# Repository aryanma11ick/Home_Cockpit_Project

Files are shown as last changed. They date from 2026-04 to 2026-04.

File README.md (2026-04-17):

# 🛫 Home Cockpit System

A custom-built **modular home cockpit system** for flight simulation, focused on replicating real aircraft controls using **PCB design, CAD modeling, and embedded systems**.

This project combines **hardware engineering + software integration** to create a scalable and realistic cockpit environment.

---

## ✈️ Overview

The goal of this project is to design a **high-fidelity, modular cockpit system** that closely mimics real aircraft panels while remaining flexible for expansion.

Key design principles:

* 🔧 **Modularity** – Panels can be developed and used independently
* 🧩 **Scalability** – Easy to expand into a full cockpit
* 🎯 **Realism** – Accurate switch behavior and layout
* ⚡ **Integration** – Seamless connection with flight simulators

---

## 🧱 Project Structure

```text
hardware/
├── pcb/          # KiCad design files + Gerbers
└── cad/          # STEP/STL files for panels and components

firmware/         # Microcontroller code (Arduino / ESP32)

software/         # Simulator interface plugins (X-Plane, etc.)

docs/             # Documentation, diagrams, and images
```

---

## 🔧 Modules

### 🟢 Overhead External Lights Panel

* Fully functional external lighting control panel
* Supports multiple 3-position and 2-position switches
* Integrated with simulator via custom plugin
* Designed for real-time hardware ↔ simulator synchronization

---

### 🟡 Annunciator (Alert) Panel

* Displays aircraft alerts and system states
* Uses custom illuminated switches
* Modular layout for future expansion

---

### 🔘 Korry Switch Module (v2)

* Custom PCB designed in KiCad
* LED backlighting support
* Reusable module for multiple panels
* Includes CAD models for enclosure and mounting

---

## ⚙️ Technologies Used

### 🧠 Hardware

* **KiCad** – PCB design and layout
* **Fusion 360 / CAD tools** – Mechanical design and panel modeling

### 💻 Software

* **C++ (X-Plane SDK)** – Simulator interface plugins
* **Arduino / ESP32** – Firmware and hardware control

### 🔗 Tools

* **GitHub** – Version control and project management

---

## 🔁 System Architecture

```text
[Physical Switches] → [Microcontroller] → [Serial Communication]
                                  ↓
                            [Plugin / Interface]
                                  ↓
                             [Flight Simulator]
                                  ↑
                          [DataRef Feedback Loop]
```

* Closed-loop system ensures **hardware and simulator stay synchronized**
* Supports **real-time control and feedback**

---

## 🚧 Project Status

**Status:** 🟢 Active Development

### ✅ Completed

* Korry Switch PCB (v2)
* Initial CAD panel designs
* Overhead external lights panel (hardware + integration)

### 🔄 In Progress

* Firmware refinement
* Panel integration and wiring
* Simulator interface improvements

---

## 📸 Media

### Hardware Preview

<p align="center">
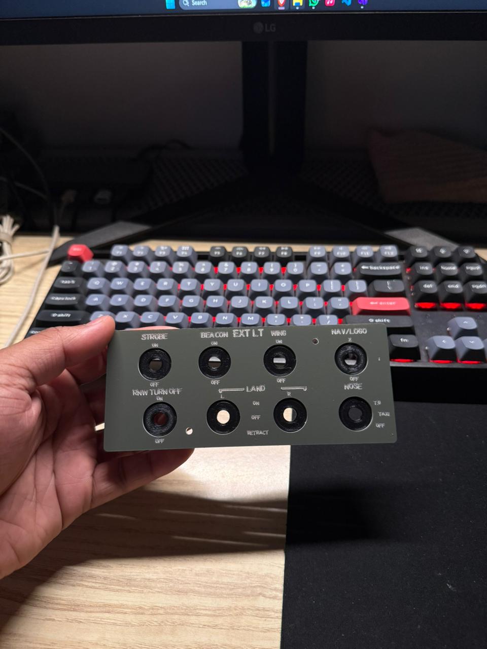
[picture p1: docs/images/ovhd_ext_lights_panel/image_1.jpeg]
  
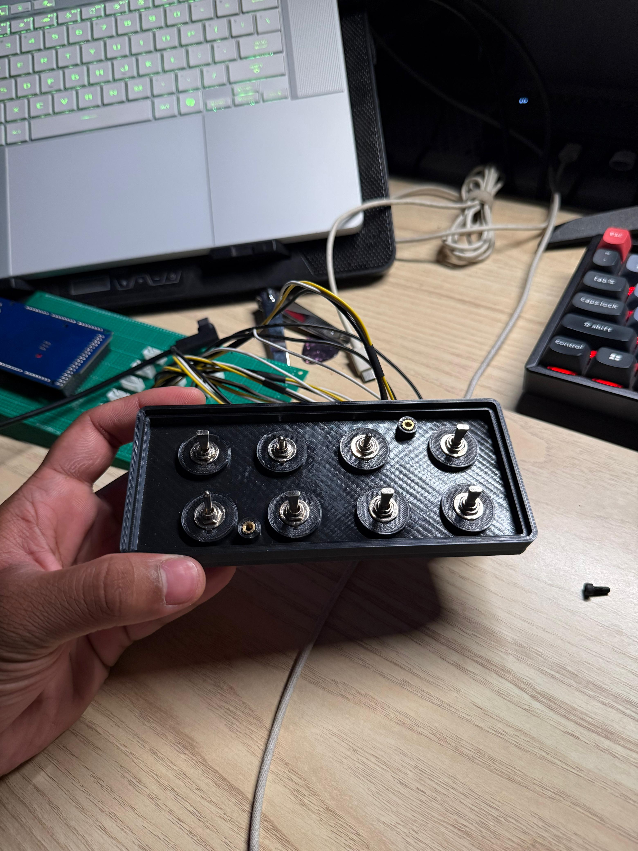
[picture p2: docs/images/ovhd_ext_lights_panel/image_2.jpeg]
  
</p>

<p align="center">
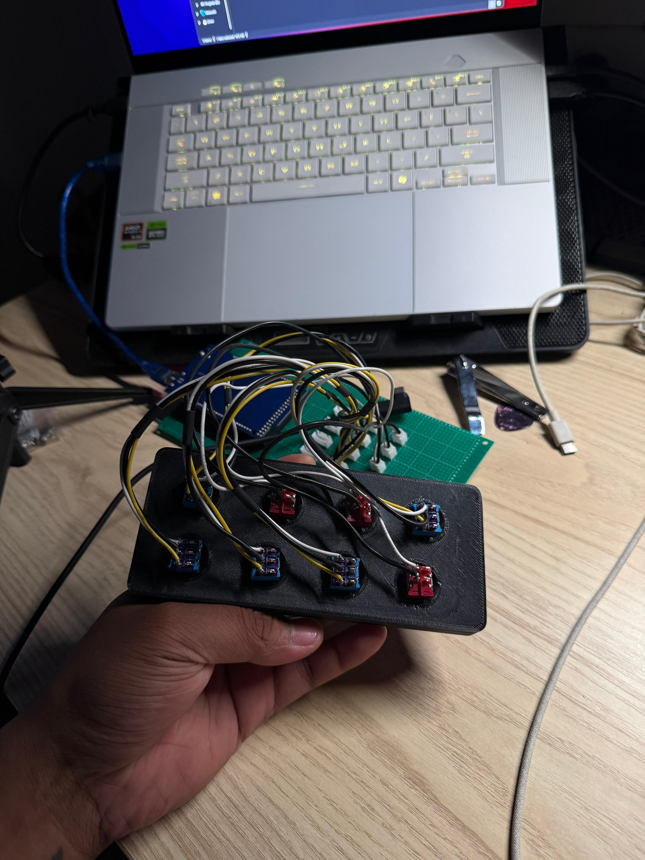
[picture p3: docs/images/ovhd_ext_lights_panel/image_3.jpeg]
  
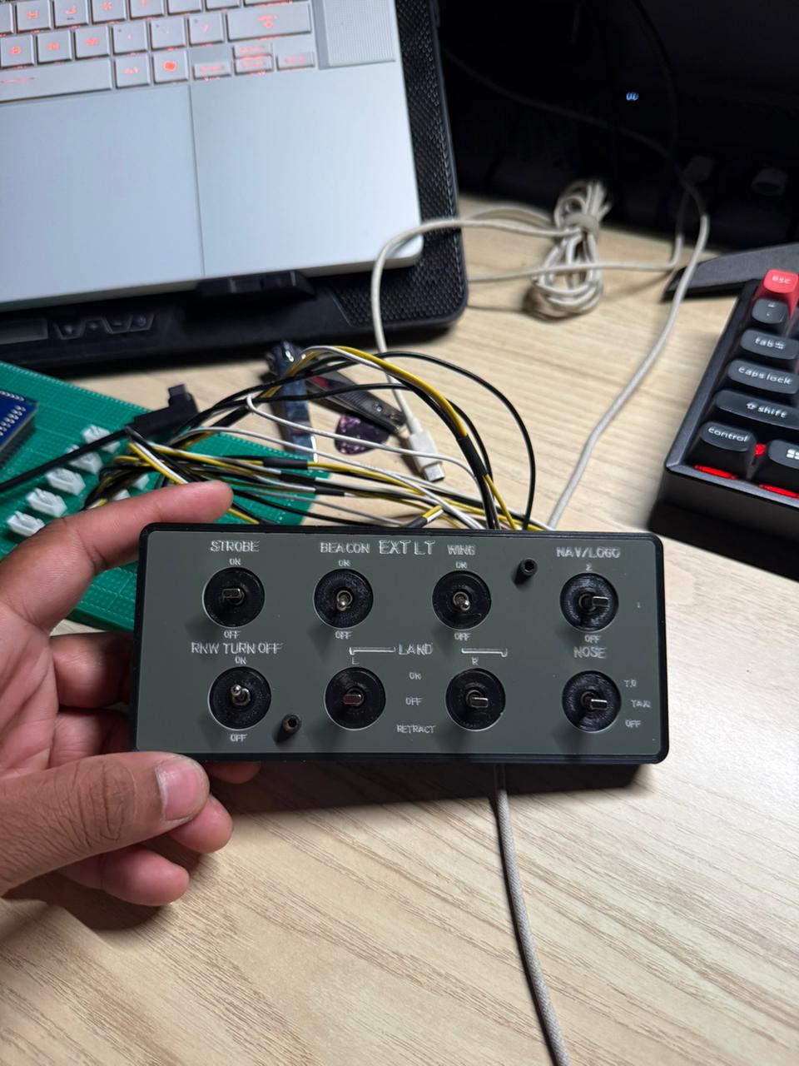
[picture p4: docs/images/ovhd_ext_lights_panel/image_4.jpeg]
  
</p>

<p align="center">
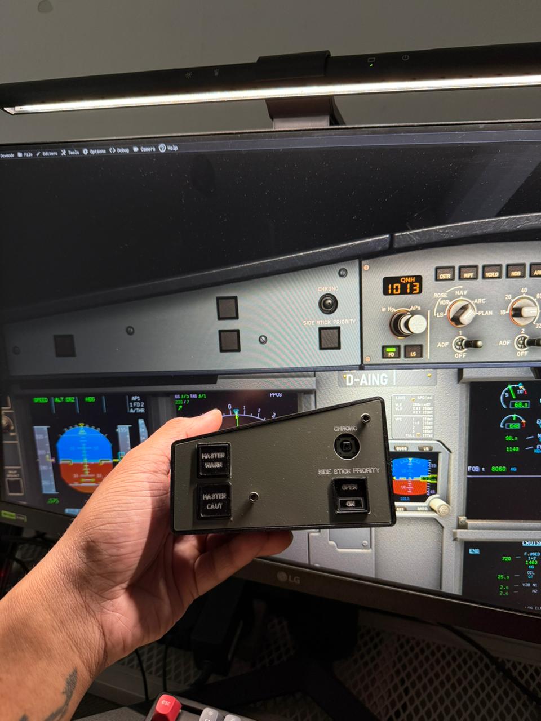
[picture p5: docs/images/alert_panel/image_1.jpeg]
  
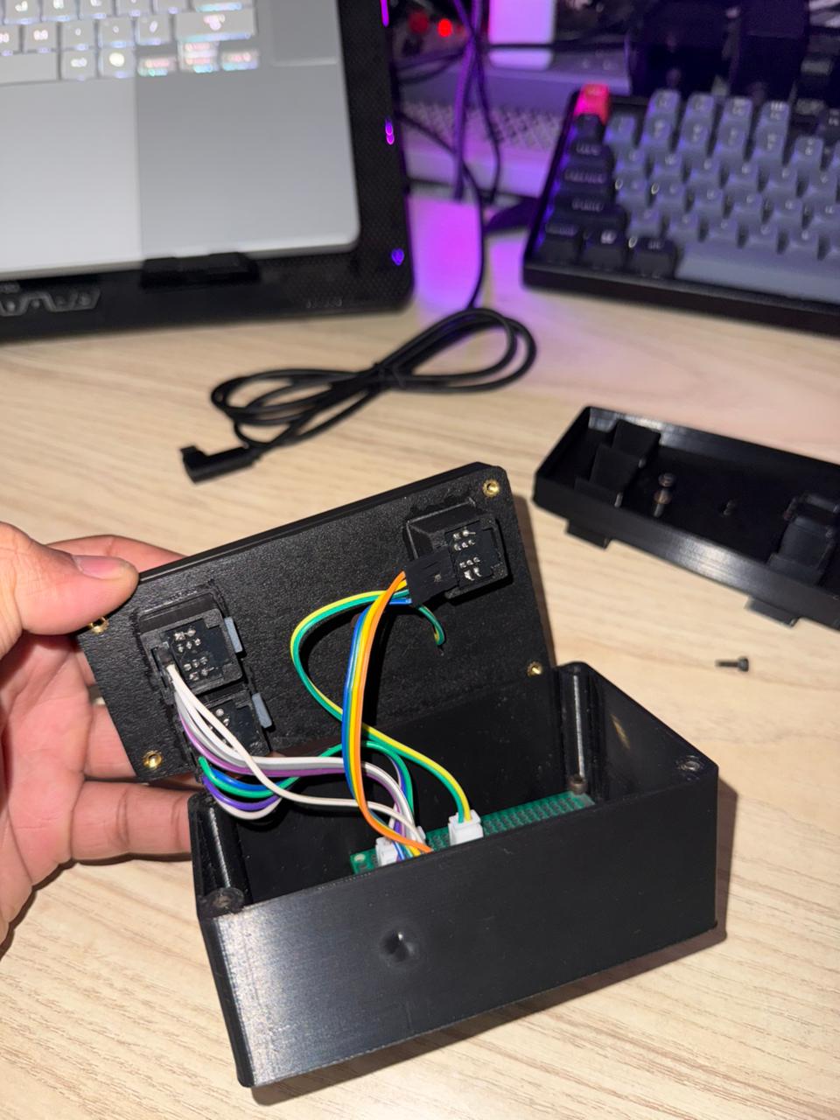
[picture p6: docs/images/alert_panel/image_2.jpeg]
  
</p>

<p align="center">
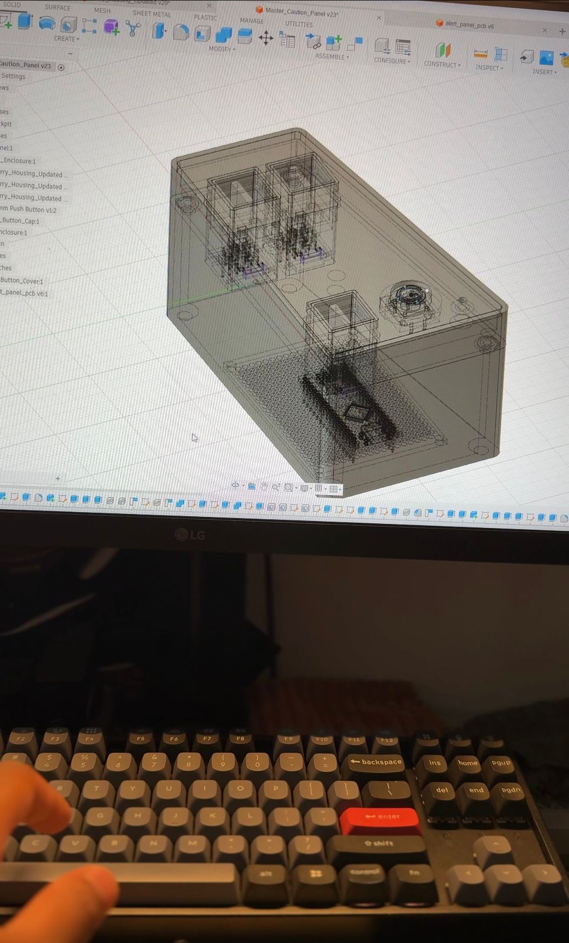
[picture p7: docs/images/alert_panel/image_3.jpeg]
  
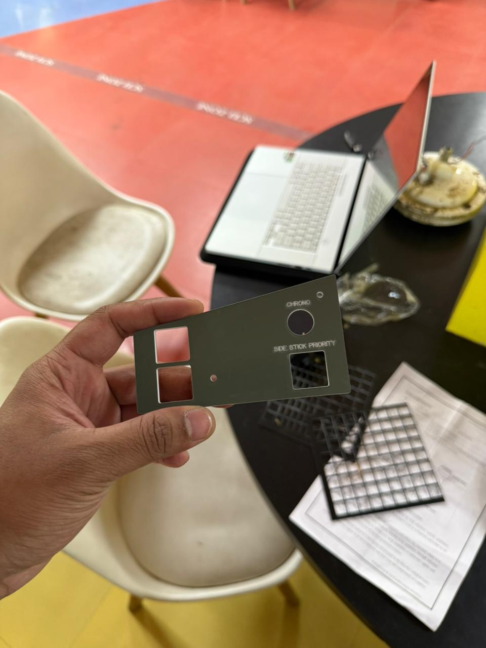
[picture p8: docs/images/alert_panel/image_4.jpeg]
  
</p>

---

## 🚀 Future Plans

* Enhanced backlighting and light diffusion
* Full overhead panel completion
* Additional cockpit modules (FCU, MCDU, etc.)
* Improved simulator integration and feedback systems
* Expansion to a complete cockpit build

---

## 👤 Author

**Aryan Mallick**
Building a full-scale home cockpit system from scratch

---

## ⭐ Notes

This project is continuously evolving with improvements in:

* Hardware design
* Firmware reliability
* Simulator integration

Contributions, suggestions, and feedback are welcome.

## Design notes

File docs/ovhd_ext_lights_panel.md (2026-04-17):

# ✈️ Arduino → ToLiss A320neo Overhead Light Panel






A custom X-Plane plugin that connects a physical Arduino-based overhead panel to the ToLiss A320neo using serial communication.

This project enables real-world cockpit switches to control aircraft lighting systems with accurate, state-driven behavior using a closed-loop control system.

---

## 🔗 Project Links

### 💻 Plugin Source Code

https://github.com/aryanma11ick/Home_Cockpit_Project/blob/main/software/sim-interface/ovhd_ext_lights_panel/plugin.cpp

### 🔌 Arduino Firmware

https://github.com/aryanma11ick/Home_Cockpit_Project/blob/main/firmware/arduino/ovhd_ext_lights_panel/ovhd_ext_lights.ino

### 🖼️ Panel Images

https://github.com/aryanma11ick/Home_Cockpit_Project/tree/main/docs/images/ovhd_ext_lights_panel

---

## 📸 Hardware Preview

<p align="center">
  
  
</p>

<p align="center">
  
  
</p>
---

## 🚀 Features

### 🔌 Hardware Integration

* Arduino-based overhead panel
* Multiple switch inputs (3-position & 2-position)
* Serial communication @ 115200 baud

---

### 💡 Supported Systems

#### 🔺 3-Position Switches

* Strobe Lights
* Nav/Logo Lights
* Landing Lights (Left & Right independent)
* Nose Light (Taxi / Takeoff / Off)

#### 🔻 2-Position Switches

* Beacon Light
* Wing Light
* RWY Turn-Off Light

---

### 🔁 Closed-Loop Control System

* Uses ToLiss animation datarefs for real-time feedback
* Compares hardware state with aircraft state
* Automatically drives switches using Up/Down commands
* Prevents desynchronization between sim and hardware

---

### ⚡ Performance Optimized

* Non-blocking serial communication
* Buffered input parsing
* Low CPU usage
* No FPS drops or simulator lag

---

## 🧠 Architecture

```text
Arduino → Serial → Plugin → Commands → Aircraft
                                ↑
                          DataRefs (feedback)
```

---

## 📡 Serial Protocol

| Code | System | Values |
| ---- | --- | --- |
| S | Strobe | 0 / 1 / 2 |
| N | Nav/Logo | 0 / 1 / 2 |
| LL | Left Landing  | 0 / 1 / 2 |
| RL | Right Landing | 0 / 1 / 2 |
| O | Nose Light | 0 / 1 / 2 |
| B | Beacon | 0 / 1 |
| W | Wing | 0 / 1 |
| R | RWY Turn Off  | 0 / 1 |

### Example

```
S:2
N:1
LL:2
RL:0
O:2
B:1
W:0
R:1
```

---

## 🧩 X-Plane Integration

### ✈️ Commands (Control)

```
toliss_airbus/lightcommands/*
```

### 📊 DataRefs (State Feedback)

```
ckpt/oh/.../anim
```

---

## 🛠️ Setup

### 1. Build Plugin

* Open project in Visual Studio
* Build as **64-bit**
* Rename output:

```
win.xpl
```

---

### 2. Install Plugin

```
X-Plane 12/Resources/plugins/ArduinoSerialPlugin/64/win.xpl
```

---

### 3. Arduino Setup

* Upload firmware
* Set baud rate: **115200**
* Match COM port in plugin

---

### 4. Run

* Load ToLiss A320neo
* Enable plugin via Plugin Admin

---

## ⚠️ Notes

* RWY Turn-Off uses command-only logic (no feedback dataref)
* Designed specifically for ToLiss Airbus aircraft
* Uses animation datarefs for accurate state tracking

---

## 🔧 Future Improvements

* LED feedback to Arduino
* Auto serial reconnect
* Cold & Dark / power logic
* Full overhead expansion

---

## 👨‍💻 Author

Aryan Mallick
Home cockpit & avionics integration project

---

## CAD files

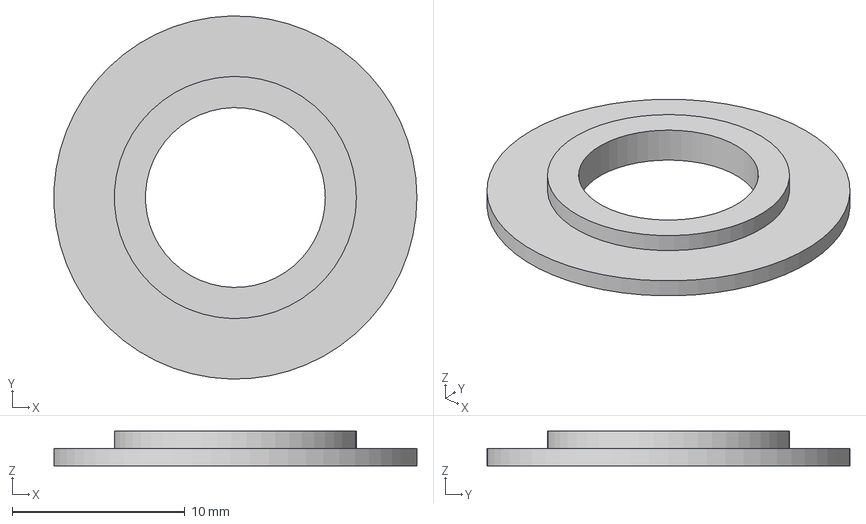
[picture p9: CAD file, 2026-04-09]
hardware/cad/step/alert_panel/chrono_button_cover.step
21.0 x 21.0 x 2.00 mm

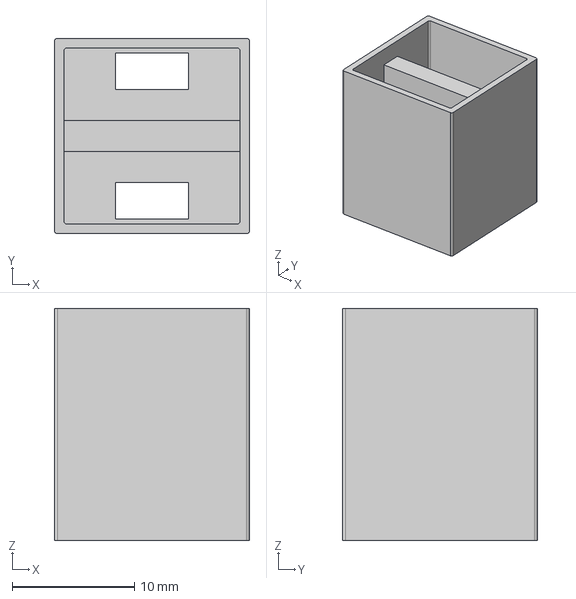
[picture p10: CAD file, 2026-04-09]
hardware/cad/step/korry_button/internal_shell.step
16.0 x 16.0 x 19.0 mm

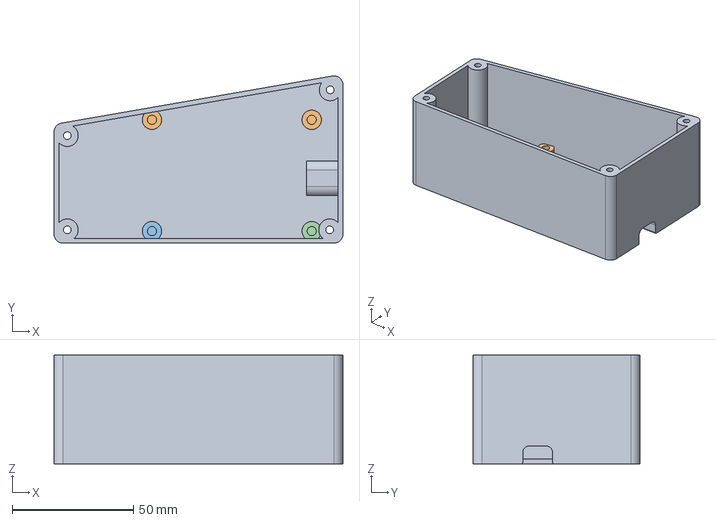
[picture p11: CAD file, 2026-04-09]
hardware/cad/step/alert_panel/back_enclosure.step
119.4 x 69.1 x 45.0 mm

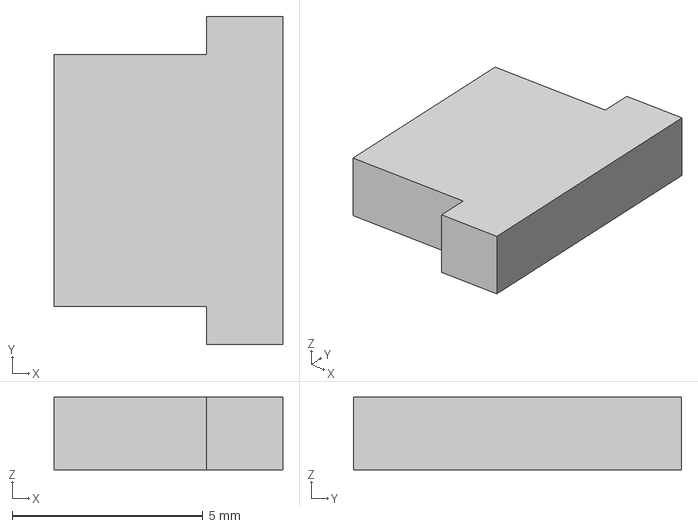
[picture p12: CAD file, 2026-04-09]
hardware/cad/step/korry_button/pcb_lock.step
6.00 x 8.60 x 1.90 mm

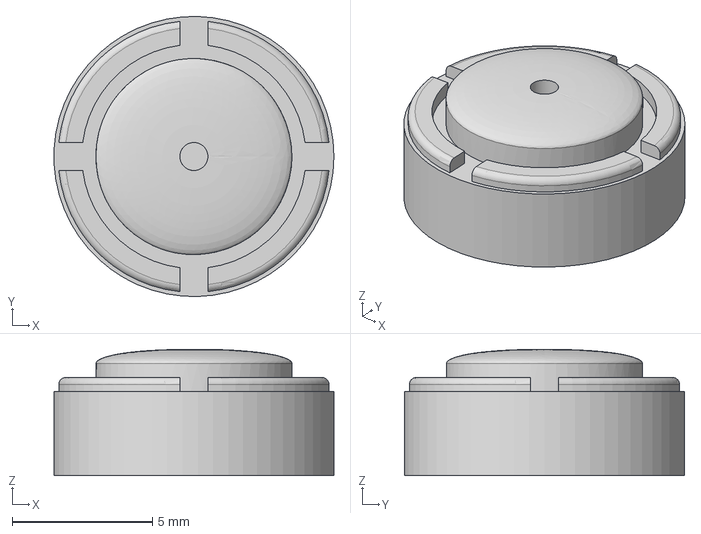
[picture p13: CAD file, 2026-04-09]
hardware/cad/step/alert_panel/chrono_button_cap.step
9.99 x 10.00 x 4.50 mm

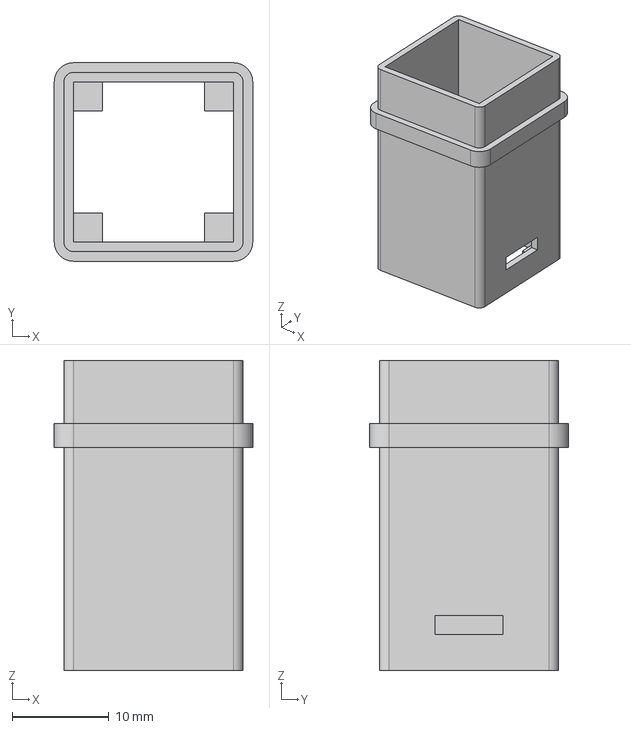
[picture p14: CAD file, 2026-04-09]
hardware/cad/step/korry_button/external_shell.step
20.5 x 20.5 x 32.0 mm

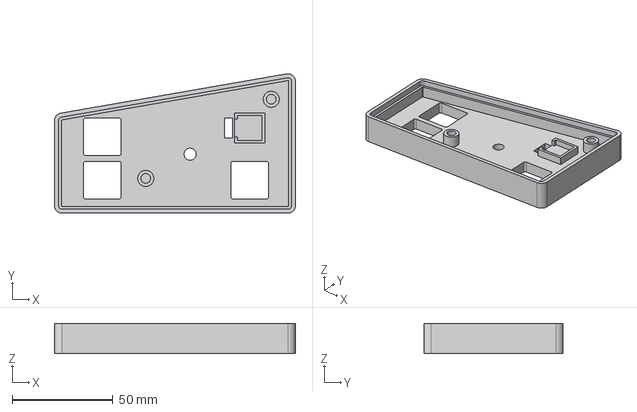
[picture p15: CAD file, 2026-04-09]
hardware/cad/step/alert_panel/middle_enclosure.step
119.4 x 69.1 x 15.0 mm

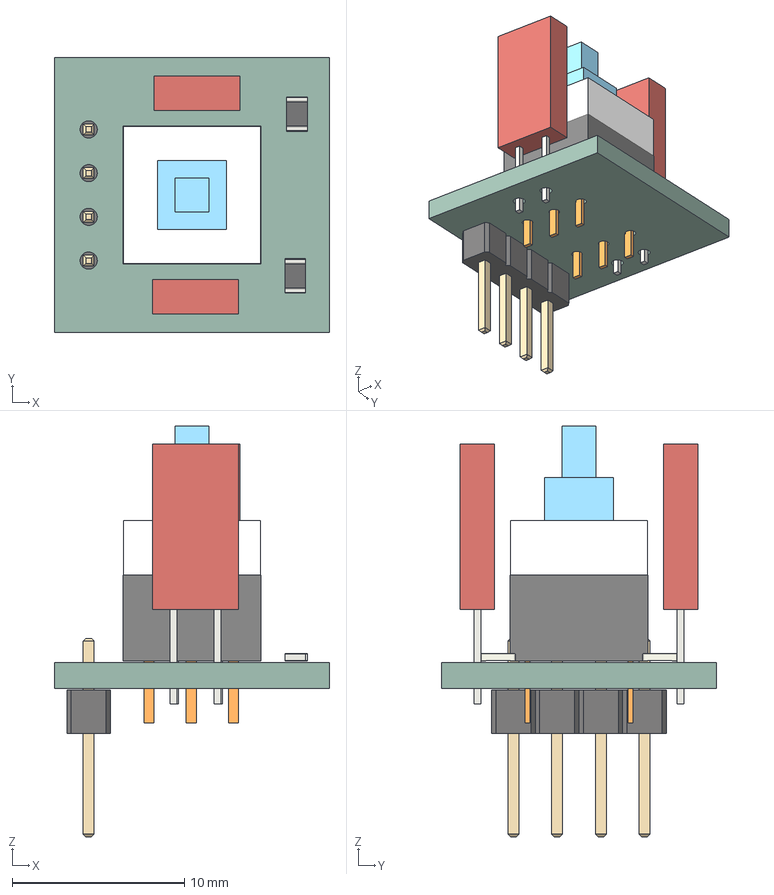
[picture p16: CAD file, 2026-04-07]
hardware/cad/step/korry_button/korry_pcb.step
16.0 x 16.0 x 23.9 mm
R_0805_2012Metric x 2
LED_Rectangular_W5.0mm_H2.0mm x 2
SW_Btn_XLX
PinHeader_1x04_P2.54mm_Vertical
korry_pcb_v2_PCB

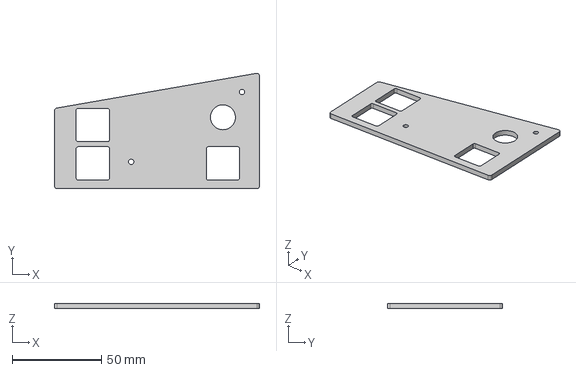
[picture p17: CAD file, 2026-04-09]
hardware/cad/step/alert_panel/top_panel.step
115.0 x 64.7 x 3.00 mm

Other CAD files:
hardware/cad/fusion360/alert_panel/Alert_Panel.f3z
hardware/cad/fusion360/korry_button/Korry_Button_Assembly.f3z
hardware/cad/fusion360/ovhd_ext_lights_panel/OVHD_External_Lights_Panel.f3z

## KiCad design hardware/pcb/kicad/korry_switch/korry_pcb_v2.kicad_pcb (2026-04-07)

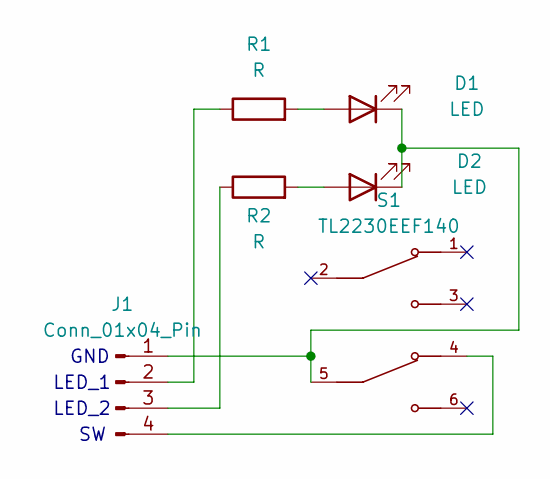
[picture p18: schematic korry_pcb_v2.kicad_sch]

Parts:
D1, D2: LED; LED_Rectangular_W5.0mm_H2.0mm
J1: Conn_01x04_Pin; PinHeader_1x04_P2.54mm_Vertical
R1, R2: R; R_0805_2012Metric_Pad1.20x1.40mm_HandSolder
S1: TL2230EEF140; SW_TL2230EEF140; PARTREV E

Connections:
unnamed: D1.2 (A), R1.2
unnamed: D1.1 (K), D2.1 (K), J1.1, S1.5
unnamed: D2.2 (A), R2.2
unnamed: J1.2, R1.1
unnamed: J1.3, R2.1
unnamed: J1.4, S1.4

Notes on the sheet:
LED_2
LED_1
GND

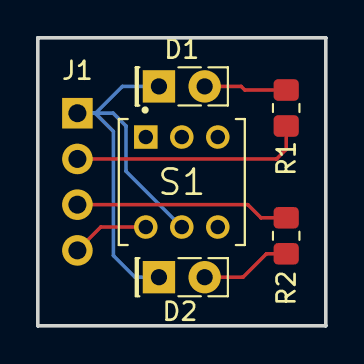
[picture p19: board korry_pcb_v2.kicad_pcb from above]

Board: 2 copper layers, 16.0 x 16.0 mm, 6 parts (1 on the bottom side), 6 nets.

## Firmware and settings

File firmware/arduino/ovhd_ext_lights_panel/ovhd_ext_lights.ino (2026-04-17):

// =============================================
// A333 OVERHEAD LIGHT PANEL (FINAL)
// =============================================

// -------- 3-POS SWITCHES --------
const int STROBE_UP   = 46;
const int STROBE_DOWN = 48;

const int NAV_UP   = 32;
const int NAV_DOWN = 30;

const int L_LAND_UP   = 44;
const int L_LAND_DOWN = 42;

const int R_LAND_UP   = 40;
const int R_LAND_DOWN = 38;

const int NOSE_UP   = 36;  // TAKEOFF
const int NOSE_DOWN = 34;  // TAXI

// -------- 2-POS SWITCHES --------

const int WING   = 24;
const int BEACON = 26;
const int RWY    = 28;

// -------- STATE MEMORY --------
int lastS  = -1;
int lastN  = -1;
int lastLL = -1;
int lastRL = -1;
int lastO  = -1;

int lastB = -1;
int lastW = -1;
int lastR = -1;

void setup() {
  Serial.begin(115200);

  // 3-pos
  pinMode(STROBE_UP, INPUT_PULLUP);
  pinMode(STROBE_DOWN, INPUT_PULLUP);

  pinMode(NAV_UP, INPUT_PULLUP);
  pinMode(NAV_DOWN, INPUT_PULLUP);

  pinMode(L_LAND_UP, INPUT_PULLUP);
  pinMode(L_LAND_DOWN, INPUT_PULLUP);

  pinMode(R_LAND_UP, INPUT_PULLUP);
  pinMode(R_LAND_DOWN, INPUT_PULLUP);

  pinMode(NOSE_UP, INPUT_PULLUP);
  pinMode(NOSE_DOWN, INPUT_PULLUP);

  // 2-pos
  pinMode(BEACON, INPUT_PULLUP);
  pinMode(WING,   INPUT_PULLUP);
  pinMode(RWY,    INPUT_PULLUP);
}

void loop() {

  // -------- 3-POS --------
  handle3Pos("S",  STROBE_UP, STROBE_DOWN, lastS);
  handle3Pos("N",  NAV_UP, NAV_DOWN, lastN);
  handle3Pos("LL", L_LAND_UP, L_LAND_DOWN, lastLL);
  handle3Pos("RL", R_LAND_UP, R_LAND_DOWN, lastRL);
  handle3Pos("O",  NOSE_UP, NOSE_DOWN, lastO);

  // -------- 2-POS (REVERSED) --------
  handle2Pos("B", BEACON, lastB);
  handle2Pos("W", WING,   lastW);
  handle2Pos("R", RWY,    lastR);

  delay(20);
}

// =============================================
// 3-POS HANDLER
// =============================================
void handle3Pos(const char* label, int pinUp, int pinDown, int &lastState) {
  bool up   = !digitalRead(pinUp);
  bool down = !digitalRead(pinDown);

  int state = -1;

  if (up && !down) state = 2;
  else if (!up && !down) state = 1;
  else if (!up && down) state = 0;

  if (state != lastState && state != -1) {
    lastState = state;
    Serial.print(label);
    Serial.print(":");
    Serial.println(state);
  }
}

// =============================================
// 2-POS HANDLER (REVERSED)
// =============================================
void handle2Pos(const char* label, int pin, int &lastState) {

  // reversed logic
  int state = digitalRead(pin);

  if (state != lastState) {
    lastState = state;
    Serial.print(label);
    Serial.print(":");
    Serial.println(state);
  }
}

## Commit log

2026-04-07 gerber files for the korry buttons pcb
2026-04-07 KiCad Files of the Korry Buttons PCB
    [korry_pcb_v2.kicad_pcb, korry_pcb_v2.kicad_sch]
2026-04-07 Korry Button PCB 3D Model
    [korry_pcb_v2.step]
2026-04-07 Rename Korry PCB file to korry_pcb.kicad_pcb
    [korry_pcb.kicad_pcb]
2026-04-09 Korry Switch KiCad Files
    [korry_pcb_v2.kicad_pcb, korry_pcb_v2.kicad_sch]
